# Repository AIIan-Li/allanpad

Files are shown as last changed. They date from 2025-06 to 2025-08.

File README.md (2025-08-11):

# allanpad

Allanpad is a 9 key macropad with a rotary encoder, and uses KMK firmware.

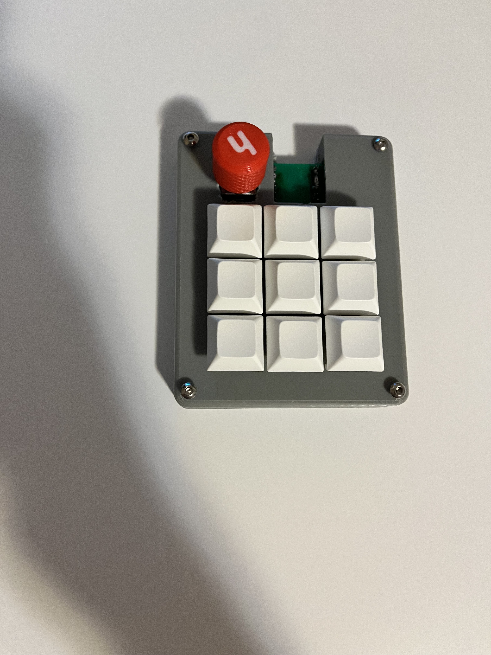
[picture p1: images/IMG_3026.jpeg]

## Features:
-3d printed case
-EC 11 Rotary encoder
-9 Keys

## CAD Model:
Everything goes together with 4 M3 screws for the case

It has the bottom part where the pcb goes and the top cover for it.

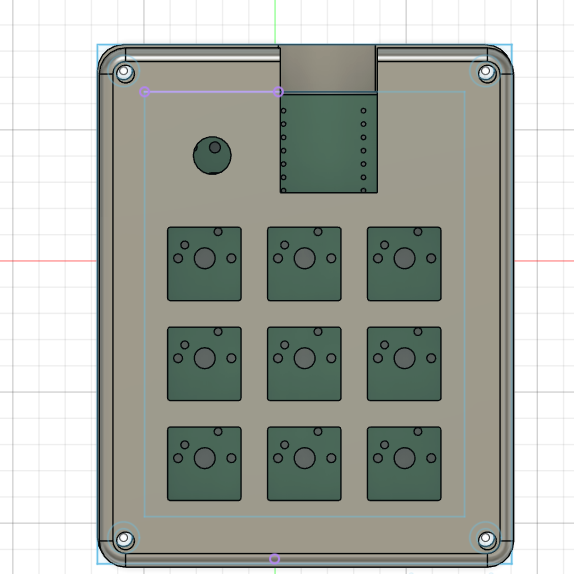
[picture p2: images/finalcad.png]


Made in Fusion360

## PCB
The PCB was created in KICAD

Schematic
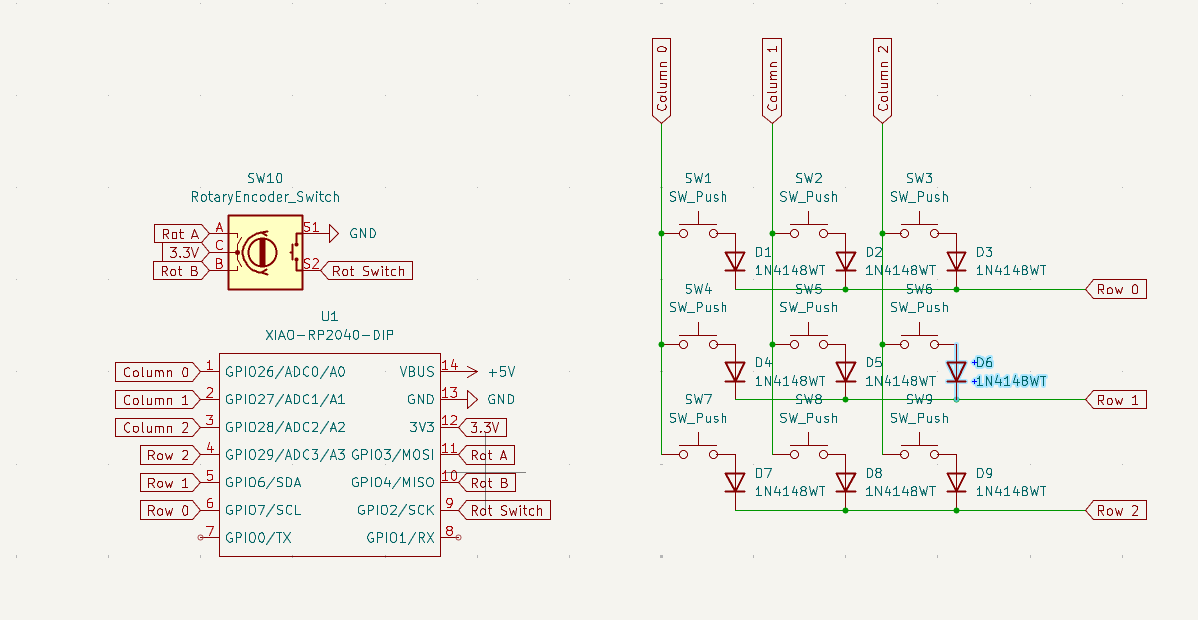
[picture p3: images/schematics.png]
schematic


PCB
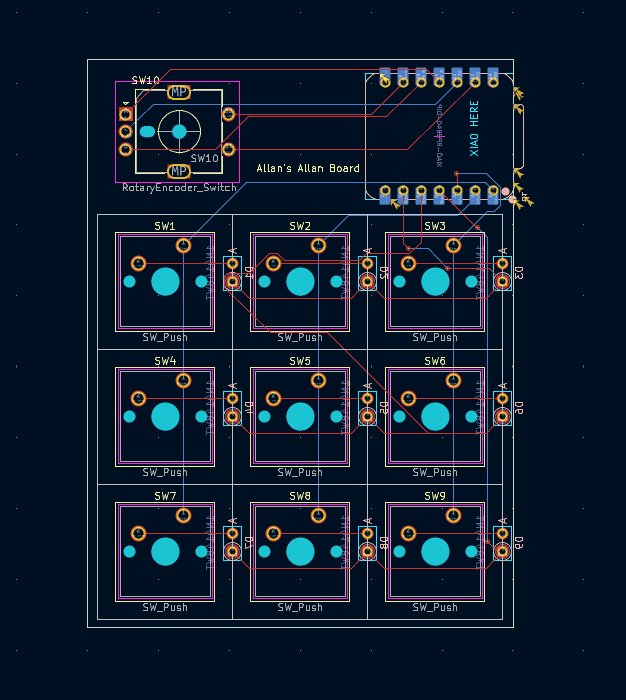
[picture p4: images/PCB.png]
PCB complete


## Firmware Overview
The hackpad uses kmk firmware for everything

- the rotary encoder changes volume. press to mute
- The 9 keys are macros that I can change

## BOM:
Everything needed to make the macropad

- 9x Cherry MX Switches
- 9x DSA Keycaps
- 4x M3x5x4 Heatset inserts
- 4x x16mm SHCS Bolts
- 9 1N4148 DO-35 Diodes.
- 1x EC11 Rotary Encoder
- 1x XIAO RP2040
- 1x Case (2 printed parts)

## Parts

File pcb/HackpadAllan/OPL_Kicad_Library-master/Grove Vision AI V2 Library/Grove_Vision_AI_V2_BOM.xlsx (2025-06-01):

Layer Jump | Number | Name | Specification | Operating Temperature | MPN Code | Quantity | Base | Plug Position | Process
N | 301010000 | SMD RES 0R-5%-1/16W;0402 |  | -55°C to 155°C | RC0402JR-070RL | 3 | 1 | R29,R30,R39 | SMT1
N | 301010004 | SMD RES 10K-5%-1/16W;0402 |  | -55°C to 155°C | RC0402JR-0710KL | 7 | 1 | R5,R7,R8,R23,R24,R31,R38 | SMT1
N | 301010008 | SMD RES 510K-5%-1/16W;0402 |  | -55°C to 155°C | RC0402JR-07510KL | 1 | 1 | R35 | SMT1
N | 301010456 | SMD RES 100K-1%-1/16W;0402 |  | -55°C to 155°C | RC0402FR-07100KL | 7 | 1 | R6,R10,R11,R16,R32,R33,R37 | SMT1
N | 301010495 | SMD RES;5.1K-1%-1/16W;0402 |  | -55°C to 155°C | RC0402FR-075K1L | 3 | 1 | R2,R3,R36 | SMT1
N | 301010746 | SMD RES 2.2K-1%-1/16W;0402 |  | -55°C to 155°C | RC0402FR-072K2L | 10 | 1 | R1,R4,R13,R14,R15,R19,R20,R21,R22,R40 | SMT1
N | 301011331 | SMD RES 22.1K-1%-1/16W;0402 |  | -55°C to 155°C | RC0402FR-0722K1L | 2 | 1 | R26,R34 | SMT1
N | 302010004 | SMD CAP Ceramic 100nF-16V-10%-X7R;0402 |  | -55°C to 125°C | CC0402KRX7R7BB104 | 18 | 1 | C5,C8,C13,C20,C21,C22,C23,C24,C25,C26,C27,C29,C30,C31,C32,C35,C36,C39 | SMT1
N | 302010006 | SMD CAP Ceramic 10nF-50V-10%-X7R;0402 |  | -55°C to 125°C | CC0402KRX7R9BB103 | 1 | 1 | C3 | SMT1
N | 302010049 | SMD CAP Ceramic 12pF-50V-5%-NPO;0402 |  | -55°C to 125°C | CC0402JRNPO9BN120 | 2 | 1 | C14,C15 | SMT1
N | 302010051 | SMD CAP Ceramic 220nF-16V-10%-X7R;0402 |  | -55°C to 125°C | CC0402KRX7R7BB224 | 1 | 1 | C16 | SMT1
N | 302010407 | SMD CAP Ceramic 4.7uF-10V-10%-X5R;0402 |  | -55°C to 85°C | CC0402KRX5R6BB475 | 7 | 1 | C4,C6,C7,C9,C10,C28,C34 | SMT1
N | 302010519 | SMD CAP Ceramic 10uF-10V-20%-X5R;0402 |  | -55°C to 85°C | CC0402MRX5R6BB106 | 2 | 1 | C11,C37 | SMT1
N | 302013249 | SMD CAP Ceramic 1uF-10V-10%-X5R;0402 |  | -55°C to 85°C | CL05A105KP5NNNC | 5 | 1 | C1,C2,C17,C18,C19 | SMT1
N | 303010544 | SMD Inductor 4.7uH-20%-1.1A;0806 |  | -40°C to 105°C | VLS201610HBX-4R7M-1 | 1 | 1 | L1 | SMT1
N | 303011858 | SMD Inductor 470nH-20%-2.6A;0603 |  | -40°C to 125°C | TFM160808ALC-R47MTAA | 2 | 1 | L2,L3 | SMT1
N | 304011053 | SMD Diode Schottky 40V-1A;SOD-323 |  |  | B5819WS SL | 4 | 1 | D1,D2,D3,D4 | SMT1
N | 304090121 | SMD LED Clear-Green;0402 | As posted |  | BL-HGE37A-AV-TRB | 1 | 1 | LED2 | SMT1
N | 304090746 | SMD LED Clear-Yellow;0402 | As posted |  | 16-213/Y2C-AN2Q1B/3T | 1 | 1 | LED1 | SMT1
N | 305030071 | SMD MOSFET N-CH 20V-500mA;SOT-523 |  |  | CJ1012 | 5 | 1 | Q1,Q2,Q3,Q4,Q5 | SMT1
N | 306011444 | SMD Crystal;24MHz-12pF-10ppm-4P-2.0*1.6*0.5mm |  | -40°C to 85°C | Y2400FE001 | 1 | 1 | X1 | SMT1
N | 310011697 | SMD IC MCU;Dual Cortex-M55 Core(Max 400MHz)-With a 400MHz NPU;WLCSP-65 | L5.58*W2.27mm | -40°C to 85°C | HX6538-A01TWA | 1 | 1 | U1 | SMT1
N | 310032794 | SMD IC PMIC;DCDC Buck-ADJ-2.2MHz-4A;DFN1.5×1.5-6 |  | -40°C to 85°C | SY80004DQD | 2 | 1 | U4,U6 | SMT1
N | 310032813 | SMD IC PMIC;LDO-1.8V-300mA;XTDFN-1*1-4L |  | -40°C to 125°C | SGM2036S-1.8XXDH4G/TR | 1 | 1 | U3 | SMT1
N | 310071431 | SMD IC Interface USB to High Speed TTL;QFN16 | USB to High-Speed Serial Port | -40°C to 85°C | CH343P | 1 | 1 | U2 | SMT1
N | 310091468 | SMD IC Memory;128Mbit-1.8V;SOIC-8 |  | -40°C to 85°C | W25Q128JWSIQ | 1 | 1 | U5 | SMT1
N | 311020009 | SMD Top Button 4N;4P-L4.6*W3.2*H2.5mm |  | -20°C to 70°C | SKRPADE010 | 1 | 1 | RST1 | SMT1
N | 311020518 | SMD Top Button 1.57N;4P-L4.6*W3.2*H2.5mm |  | -30°C to 85°C | SKRPABE010 | 1 | 1 | BOOT1 | SMT1
N | 312030502 | SMD DIGITAL MIC OMNI -26dBFS;OCLGA-4:3.5*2.65*0.94mm |  | -40˚C to 100˚C | MSM261D3526H1CPM | 1 | 1 | MIC1 | SMT1
N | 319015667 | PCB;Grove - Vision AI Module V2 -蓝油白字-4层 | 20*40*1.6mm-ENIG-FR4;Steel mesh code；404012305 |  |  | 1 | 1 |  | SMT1
N | 320011358 | SMD USB TYPE C-W/P;12+4P-8.94*7.35*3.26mm |  | -30°C to 85°C | USB-31C-F-16P-L7.35 | 1 | 1 | J1 | SMT1
N | 320031231 | DIP Black Female Header VERT;1*7P-2.54-5.0mm |  | -40℃ to 105℃ |  | 2 | 1 | P8,P9 | Unit
N | 320060904 | SMD FPC CONN Bottom Contact;15P-1.0mm;L19.9*W6.76*H2.0mm |  | -30°C to 85°C | ST-FPC-W102015-D | 1 | 1 | J2 | SMT1
N | 320090535 | SMD uSD Card Holder;9+4P-L11.25*W6.96*H1.42mm |  | -25°C to 70°C | ST-TF-MR267 | 1 | 1 | J5 | SMT1
N | 320110032 | SMD Grove Female Header-Beige;4P-2.0-90D | 2.0-4PHorizontal Mount with Locking Socket |  | PHS-4A horizontal mount | 1 | 1 | J3 | SMT1

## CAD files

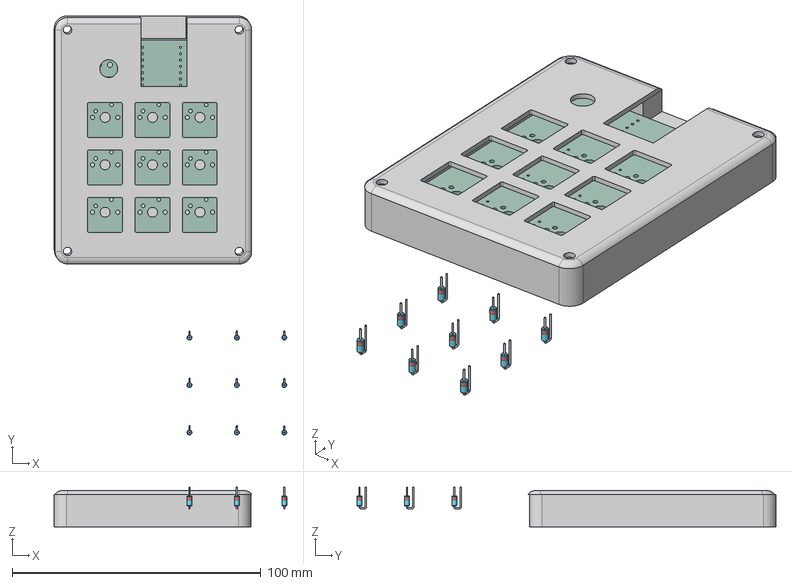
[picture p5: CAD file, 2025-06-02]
CAD/hackpad case.step
93.5 x 168.4 x 15.9 mm

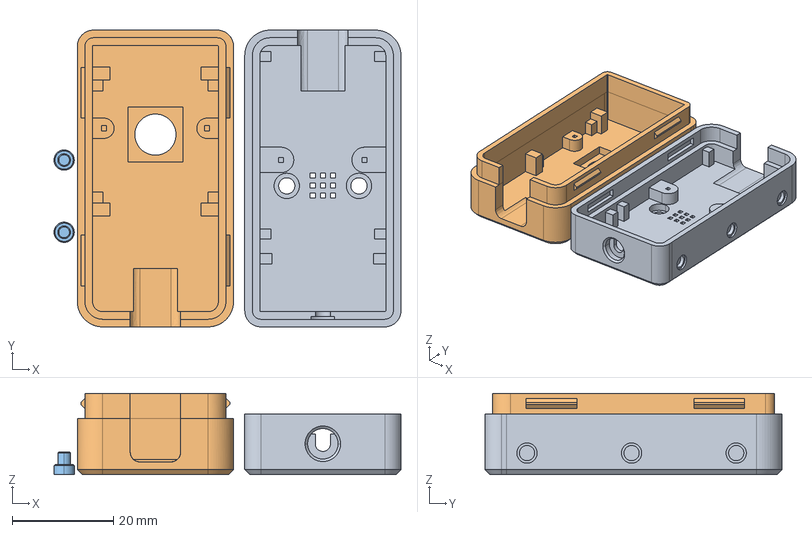
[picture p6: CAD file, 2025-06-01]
pcb/HackpadAllan/OPL_Kicad_Library-master/Grove Vision AI V2 Library/himax.stp
68.4 x 58.5 x 16.1 mm

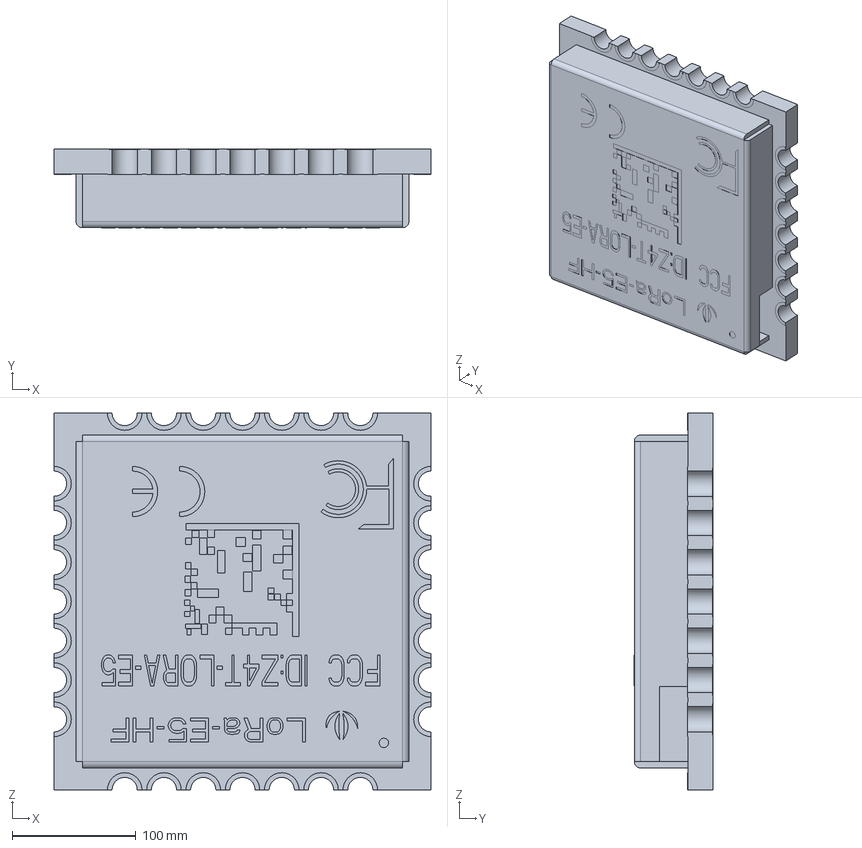
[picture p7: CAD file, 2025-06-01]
pcb/HackpadAllan/OPL_Kicad_Library-master/Seeed Studio Wio Series/Wio-E5-LE/LoRa-E5-LE-HF_3D_File.stp
304.8 x 63.8 x 304.8 mm

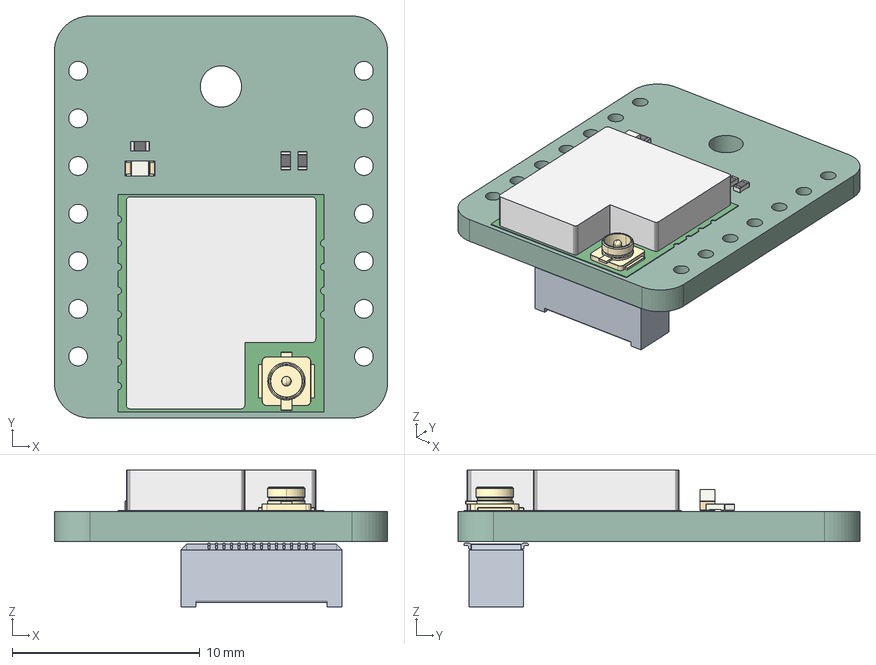
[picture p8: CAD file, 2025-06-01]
pcb/HackpadAllan/OPL_Kicad_Library-master/Seeed Studio Wio Series/Wio-SX1262/Wio-SX1262_for_XIAO_3D_file.step
17.8 x 21.4 x 7.30 mm
R_0402_1005Metric x 3
LED_0603_1608Metric
PCB
BF04-30pin-35H
Wio-SX1262 for XIAO V1.0_PCB

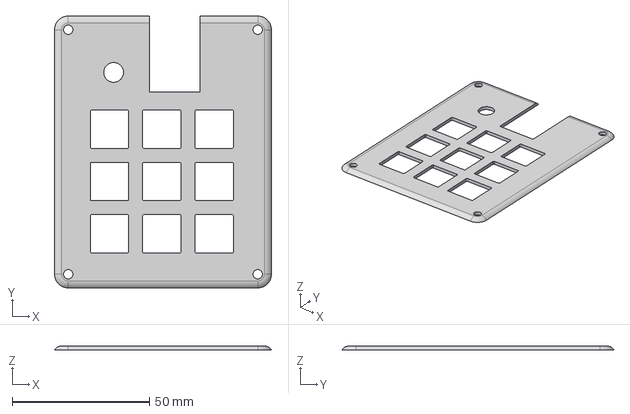
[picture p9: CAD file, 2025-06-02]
production/Case Top.step
79.0 x 99.0 x 1.50 mm

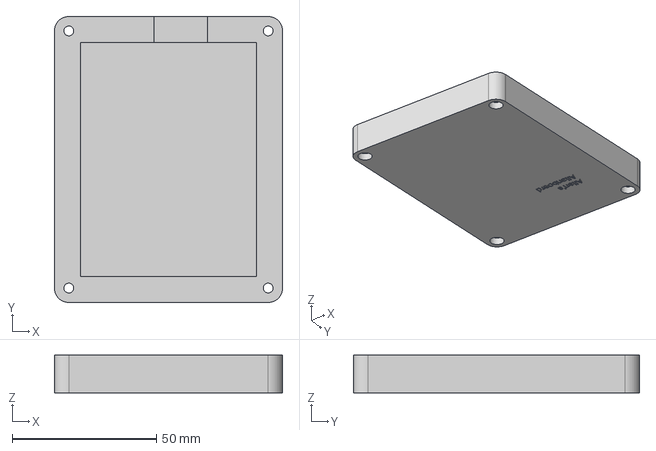
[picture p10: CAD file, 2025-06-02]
production/Case Bottom.step
79.0 x 99.0 x 13.0 mm

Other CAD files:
pcb/HackpadAllan/OPL_Kicad_Library-master/Grove Vision AI V2 Library/himax.3mf

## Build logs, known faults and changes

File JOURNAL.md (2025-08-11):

---
title: "Allanpad -Hackpad"
author: "Allan Li"
description: "a hackpad made for me, by me :)"
created_at: "2025-05-31"
---

#May 31: Making the Schematics 

Hi! this is my first ever hardware project, and although I don't believe Journaling is mandatory I thought it best to document everything. 
Finally installed OPL Kicad Library after 30 minutes, hopefully the entire process isnt this slow.
For my schematic [How to design Mechanical Keyboards PCBs with Kicad](https://www.youtube.com/watch?v=8WXpGTIbxlQ&t=320s&ab_channel=JoeScotto) was very helpful 

I knew how I wanted my macropad to look like, and after copying the HackClub tutorial exactly I decided to try again but this time creating a matrix

schematic

Honestly can say the hardest part of this was trying to find the correct footprint for the parts but I'm happy with what I learnt 
**Total time spent: 2H30min**

#May 31: Completing the PCB

At this point, I had to stop relying on tutorials and start problem solving on my own. Many things came up, especially when routing the traces.
I accidently moved the MCU then saved and closed Kicad, so wouldn't recommend as I had to reroute lots of things. 

PCB complete

**Total time spent 2H**

#May 32: Beginning the case

So I started off thinking that the case would be one of the easier steps of my process, but how wrong I was. 

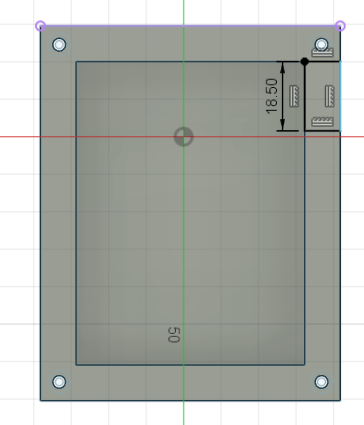
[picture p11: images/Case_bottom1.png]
Board base v1


Turns out my schematics woulddn't fit properly with the case, based off where I put the MCU and how it lined up with the holes.
I could either redesign the case, or fix the PCB which I figured would be better as to not create further problems later on. 

**Total time spent 2H**

#May 32: Refinishing the PCB

Initially It was going well, I rerouted the traces connected to the MCU, like 10 of them. 

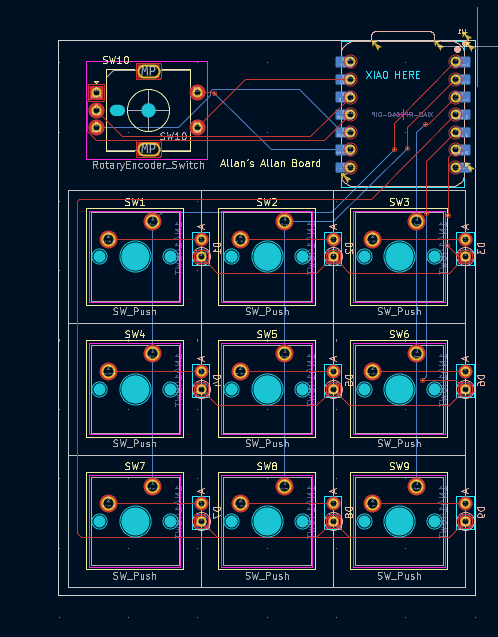
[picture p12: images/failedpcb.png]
failed PCB


Yeah so turns out I made the same mistake **again** 
I only rotated the MCU, instead of centering it to avoid interference with the case. Time to redo again.
also note: I actually made the biggest mistake ever I closed the window for some reason so I couldn't just revert my changes. 

Finally finished, I made sure to double check that nothing was going to interfere.
On the brightside, I learned a lot about routing traces, and I made sure to be more careful as I know If there was mistake I have to correct it. 

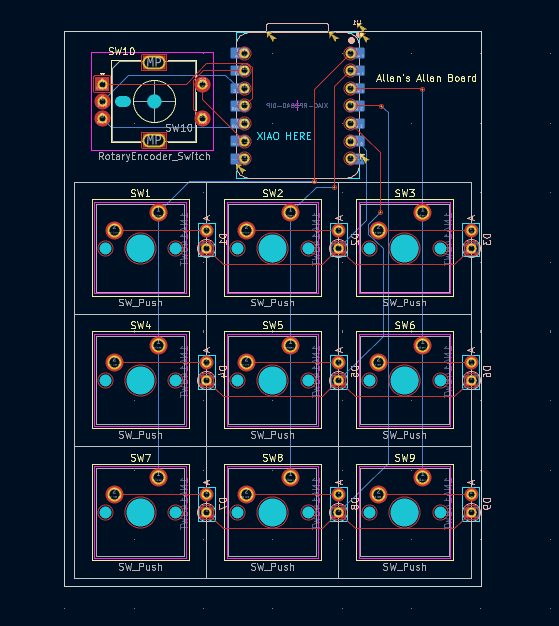
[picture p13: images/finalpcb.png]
Final Final PCB


**Total time spent 45min**

#May 32: Finishing the CAD

Mostly just working on it, not much to say



**Total time spent 2h**

#June 4: fixing my pcb 

Kind of odd, I got my project approved (please don't unapprove) then I go on hackpad website, **I used the wrong diode footprint**
Actually easier fix than I thought, I thankfully only had to reroute a few easy traces, and it doesn't impact any functions. 

pictureeee
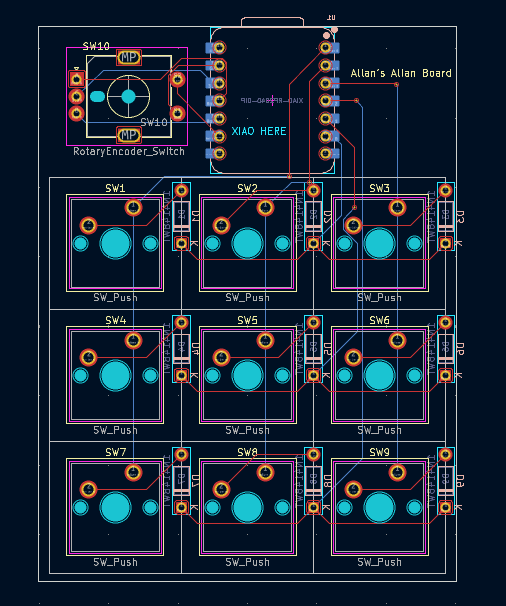
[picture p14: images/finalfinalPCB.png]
hopefully you don't need to see alt text


My gerber file for the pcb manufactuer finally got accepted after like 3 times so that's also cool
also just realised half of my journal entries are may 32 so lots of fun

**Total time spent 20min**

#July 4: doing the build

ok ik it is already into August, but when i started this project 2 months ago im like 99% sure you didn't need a journal for hackpad?? I made one anyways but here we are now and I kinda need to ship project for my travel stipend. The build was pretty easy and I can recall everything that happened but pls don't reject because I have no progress images.

So I started off by practicing soldering with one of the pcbs and a few extra switches/diodes
It was actually going pretty well so i started doing the hackpad.

It was around this point I realised I had made a circular cutout for the rotary encoder when I actually needed a square??? I thought about redoing the print but I kinda just took the solder and melted the case until the rot encoder fit. One thing I was really stupid about tho was when soldering the diodes and cutting the ends off for some reason I didn't grab the ends with a plier. Idk if that makes complete sense but basically I cut the excess of the diode off and the pieces just started flying. It's been two months and i'm still missing two pieces of wire but hopefully it isn't too bad. Other than that I didn't have any real problems with my hackpad, it was a pretty self explanatory assembly and my favourite part about it was snapping the swithces into the plate. I loaded firmware and everything was fine. Honestly don't exactly know what to talk about for the assembly cuz it just took a bit of time but wasn't actually that hard so hopefully this is detailed enough.

**Total time spent 4h**
also heres a picture of the finish product


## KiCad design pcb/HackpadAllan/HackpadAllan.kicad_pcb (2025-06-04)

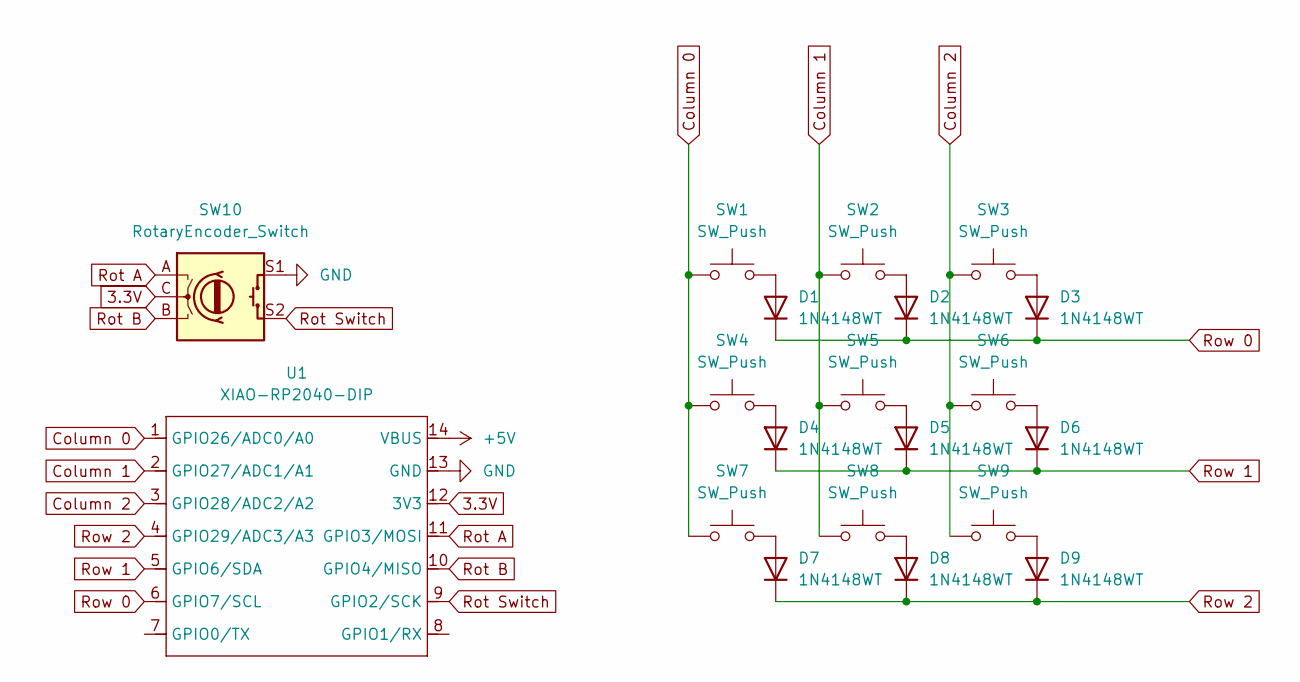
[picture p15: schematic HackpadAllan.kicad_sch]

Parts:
D1, D2, D3, D4, D5, D6, D7, D8, D9: 1N4148WT; D_DO-35_SOD27_P7.62mm_Horizontal
SW1, SW2, SW3, SW4, SW5, SW6, SW7, SW8, SW9: SW_Push; SW_Cherry_MX_1.00u_PCB
SW10: RotaryEncoder_Switch; RotaryEncoder_Alps_EC11E-Switch_Vertical_H20mm_MountingHoles
U1: XIAO-RP2040-DIP

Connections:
3.3V: SW10.C, U1.12 (3V3)
+5V: U1.14 (VBUS)
Column 0: SW1.1, SW4.1, SW7.1, U1.1 (GPIO26/ADC0/A0)
Column 1: SW2.1, SW5.1, SW8.1, U1.2 (GPIO27/ADC1/A1)
Column 2: SW3.1, SW6.1, SW9.1, U1.3 (GPIO28/ADC2/A2)
GND: SW10.S1, U1.13 (GND)
unnamed: D1.2 (A), SW1.2
unnamed: D2.2 (A), SW2.2
unnamed: D3.2 (A), SW3.2
unnamed: D4.2 (A), SW4.2
unnamed: D5.2 (A), SW5.2
unnamed: D6.2 (A), SW6.2
unnamed: D7.2 (A), SW7.2
unnamed: D8.2 (A), SW8.2
unnamed: D9.2 (A), SW9.2
Rot A: SW10.A, U1.11 (GPIO3/MOSI)
Rot B: SW10.B, U1.10 (GPIO4/MISO)
Rot Switch: SW10.S2, U1.9 (GPIO2/SCK)
Row 0: D1.1 (K), D2.1 (K), D3.1 (K), U1.6 (GPIO7/SCL)
Row 1: D4.1 (K), D5.1 (K), D6.1 (K), U1.5 (GPIO6/SDA)
Row 2: D7.1 (K), D8.1 (K), D9.1 (K), U1.4 (GPIO29/ADC3/A3)

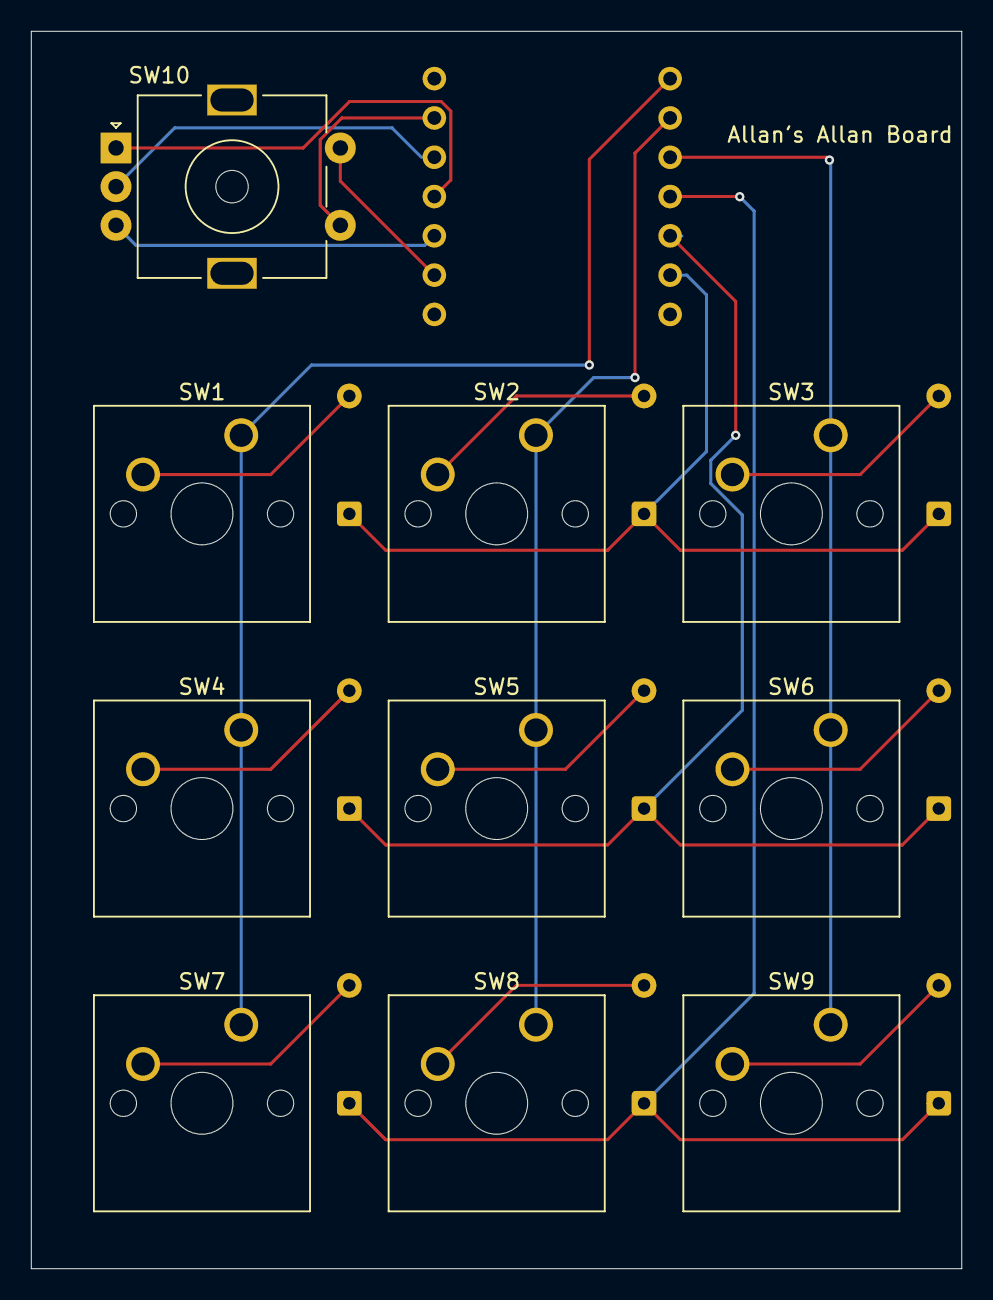
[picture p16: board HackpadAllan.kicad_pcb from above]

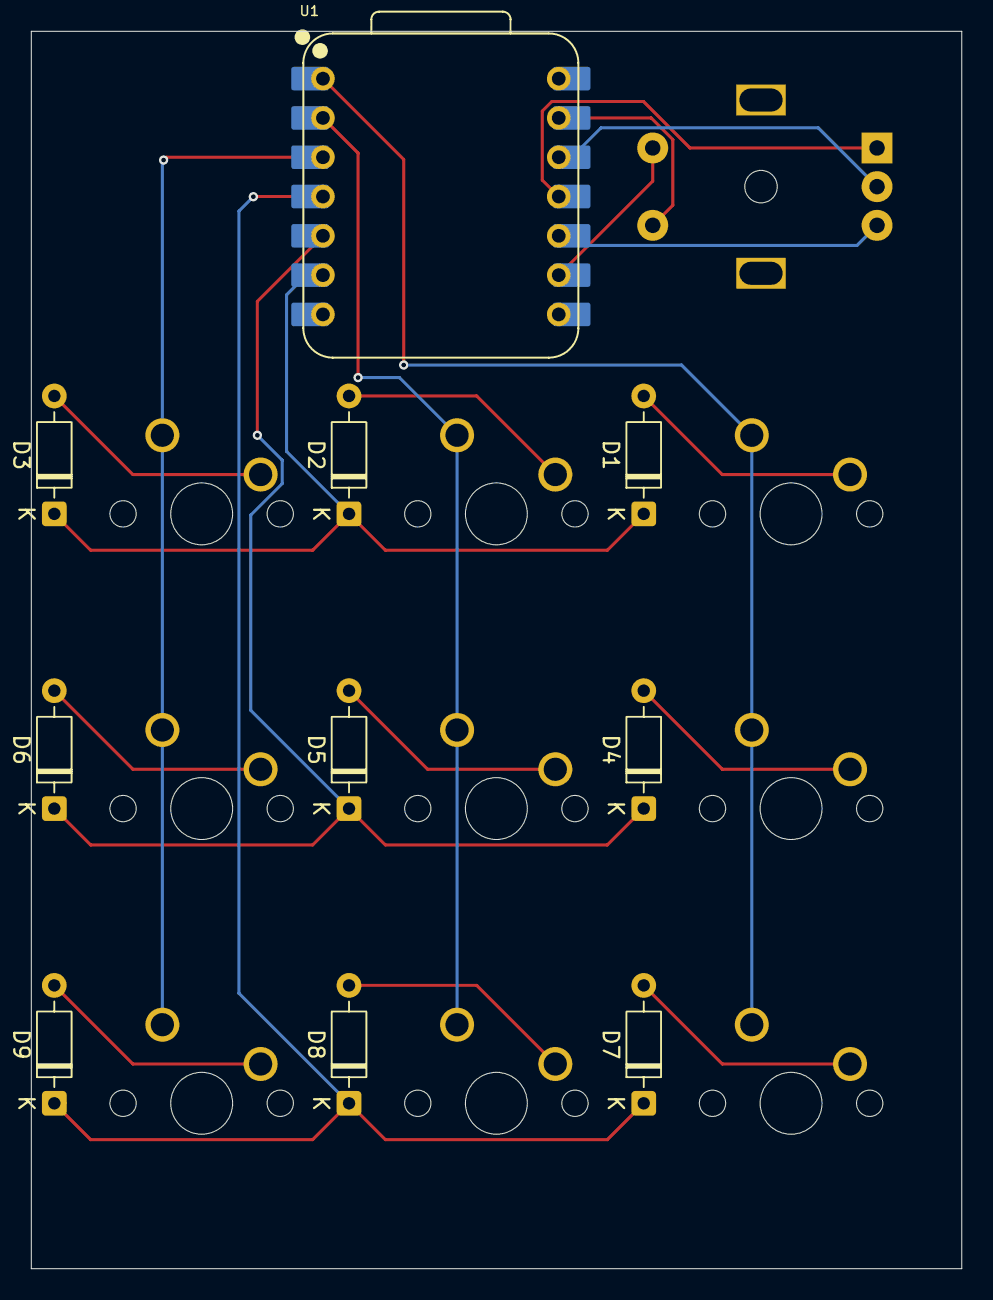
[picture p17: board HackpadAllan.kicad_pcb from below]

Board: 2 copper layers, 60.1 x 80.0 mm, 20 parts (10 on the bottom side), 20 nets.

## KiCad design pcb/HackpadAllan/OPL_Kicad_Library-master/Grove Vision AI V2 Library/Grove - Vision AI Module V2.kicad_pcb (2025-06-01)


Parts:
BOOT1: SW_Push; SW_Push_1P1T_NO_Vertical_Wuerth_434133025816
C1, C2, C17, C18, C19: 1uF; C0402
C3: 10nF; C0402
C4, C6, C7, C9, C10, C28, C34: 4.7uF; C0402
C5, C8, C13, C20, C21, C22, C23, C24, C25, C26, C27, C29, C30, C31, C32, C35, C36, C39: 100nF; C0402
C11, C37: 10uF; C0402
C14, C15: 12pF; C0402
C16: 220nF; C0402
D1, D2, D3, D4: B5819WS; D0805_SOD323
D5, D6, D7, D8: DNP; R0402; MPN DF2S6.8FS
J1: USB_C_Receptacle_USB2.0; USB2.0-TYPE-C
J2: Conn_01x15_MountingPin; FPC_DNC_15P_1.0mm
J3: Conn_01x04_MountingPin; 4P-SMD-2.0mm-RIGHT
J5: ST-TF-MR267; SD-TF-MR267; MPN SD-TF-MR267
L1: VLS201610HBX-4R7M-1; L0806
L2, L3: 470nH; L0603
LED1: Yellow; LED0402
LED2: Green; LED0402
M1: XIAO Connector/DNP; XIAO_Socket
MIC1: MSM261D3526H1CPM; MIC6P-3.5X2.65X0.94MM
Q1, Q2, Q3, Q4, Q5: CJ1012; SOT523
R1, R4, R13, R14, R15, R19, R20, R21, R22, R40: 2.2k; R0402
R2, R3, R36: 5.1k; R0402
R5, R7, R23, R24: 10k; R0402
R6, R16, R32, R33: 100K; R0402; Power Rating 1%; MPN RC0402JR-074K7L
R8, R31, R38: 10K; R0402; Power Rating 5%; MPN RC0402JR-074K7L
R9, R12, R17, R18, R25, R27, R28: DNP; R0402
R10, R11, R37: 100k; R0402
R26, R34: 22K; R0402; Power Rating 1%; MPN RC0402JR-074K7L
R29, R30, R39: 0R; R0402
R35: 510k; R0402
RST1: SW_Push; SW_Push_1P1T_NO_Vertical_Wuerth_434133025816
TP1, TP2, TP3: Test Point; TP-D35MIL; Part Type Test Point
U1: HX6538; WLCSP65_5.6x2.3x0.56mm
U2: CH343P; QFN-16-EP_3x3mm_P0.5mm_EP1x1mm
U3: WR0331-18FF4R; X2SON-4
U4, U6: SY80004DQD; DFN6-0.5-1.5X1.5X0.65MM; MPN SY80004DQD
U5: W25Q128JWSIQ; SOIC-8_5.23x5.23mm_P1.27mm
X1: 24MHz; 4P2016

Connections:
1V8: C13.1, C19.2, C20.1, C21.1, C28.1, C29.2, Q1.1 (G), Q2.1 (G), R5.1, R21.2, R22.2, R25.1, TP2.1 (T), U1.F3 (VDDIO_SIF1), U1.G3 (VDDA_RX), U1.H5 (VDDA_TX), U1.L2 (VDDIO_SIF2), U3.1 (OUT), U5.8 (VCC)
/0V9: C4.1, C7.1, L1.2, U1.L4 (DCDC_OUT)
BOOTOPT0: D3.1 (K), R11.1, U1.F4 (BOOT_OPT)
GND: C1.2, C2.2, C3.2, C4.2, C5.2, C6.2, C7.2, C8.1, C9.2, C10.2, C11.1, C13.2, C14.2, C15.1, C17.2, C18.2, C19.1, C20.2, C21.2, C22.2, C23.2, C24.1, C25.1, C26.2, C27.1, C28.2, C29.1, C30.1, C31.2, C34.2, C35.1, C37.1, C39.1, D5.1, D6.1, D7.1, D8.1, J1.A1_B1_A12_B12 (GND), J1.S1 (SHIELD), J2.1, J2.4, J2.7, J2.10, J2.MP (MountPin), J3.4, J3.MP (MountPin), J5.S1 (SHD1), J5.S2 (SHD2), J5.S3 (SHD3), J5.S4 (SHD4), J5.T6 (VSS), LED2.1 (K), M1.13 (GND), MIC1.4 (GND), MIC1.5 (L/R), MIC1.6 (GND), Q3.2 (S), R2.2, R3.2, R10.2, R11.2, R23.2, R26.1, R34.1, R37.2, RST1.2, TP3.1 (T), U1.C5 (GND1), U1.G4 (GND2), U1.H3 (GND3), U1.L3 (GND4), U1.M2 (GND5), U1.M4 (GND6), U2.2 (GND), U2.17 (EPAD), U3.2 (GND), U3.T (GND), U4.4 (GND), U5.4 (GND), U6.4 (GND), X1.2 (1), X1.4 (3)
GROVE_5V_IN: C18.1, C34.1, C35.2, J3.3, R14.1, R15.1, R31.2, R32.2, U6.6 (IN)
I2CS0_SCL/5V: J3.1, Q4.3 (D), R14.2
I2CS0_SDA/5V: J3.2, Q5.3 (D), R15.2
M_3V3_SCL: J2.13, Q1.3 (D), R19.2
M_3V3_SDA: J2.14, Q2.3 (D), R20.2
unnamed: BOOT1.2, R4.2
unnamed: D1.2 (A), R36.2
unnamed: C9.1, C10.1, C27.2, D2.1 (K), D4.1 (K), R6.2, R8.2, U4.6 (IN)
unnamed: BOOT1.1, D3.2 (A), R36.1
unnamed: J1.A5 (CC1), R2.1
unnamed: J1.B5 (CC2), R3.1
unnamed: LED1.2 (A), R38.1
unnamed: LED1.1 (K), Q3.3 (D)
unnamed: LED2.2 (A), R24.2
unnamed: M1.12 (3V3), R39.2
unnamed: MIC1.2 (CLK), R29.1
unnamed: MIC1.3 (DATA), R30.1
unnamed: Q3.1 (G), R37.1, R40.2
unnamed: R10.1, U1.E4 (TEST_MODE)
unnamed: L1.1, U1.L5 (VX1)
unnamed: C14.1, R35.1, U1.G2 (XTAL_24M_I), X1.3 (4)
unnamed: C15.2, R35.2, U1.F1 (XTAL_24M_O), X1.1 (2)
unnamed: C16.2, U2.13 (RTS)
unnamed: R8.1, U4.1 (EN)
unnamed: C32.1, R16.1, R26.2, U4.3 (FB)
unnamed: L2.1, U4.5 (LX)
unnamed: R6.1, U4.2 (PG)
unnamed: R31.1, U6.1 (EN)
unnamed: C36.1, R33.1, R34.2, U6.3 (FB)
unnamed: L3.1, U6.5 (LX)
unnamed: R32.1, U6.2 (PG)
PA0/3V3: M1.1 (D0/A0), U1.D4 (PA0)
PA1/VMUTE/3V3: J2.11, U1.C4 (PA1)
PA2/I2CS0_SCL/3V3: M1.6 (D5/SCL), Q4.2 (S), R1.1, R17.2, U1.A4 (PA2)
PA3/I2CS0_SDA/3V3: M1.5 (D4/SDA), Q5.2 (S), R13.1, R18.2, U1.B4 (PA3)
PB0/RX0/3V3: U1.A5 (PB0), U2.4 (TXD)
PB1/TX0/3V3: U1.B5 (PB1), U2.5 (RXD)
PB2/SSPIM_DO/3V3: D7.2, J5.T3 (CMD), M1.11 (D10/MOSI), R12.2, U1.N5 (PB2)
PB3/SSPIM_DI/3V3: D5.2, J5.T7 (DAT0), M1.10 (D9/MISO), R9.2, U1.M3 (PB3)
PB4/SSPIM_SCLK/3V3: D6.2, J5.T5 (CLOCK), M1.9 (D8/SCK), R27.2, U1.N4 (PB4)
PB5/SSPIM_~CS/3V3: D8.2, J5.T2 (CD/DAT3), R28.2, U1.N3 (PB5)
PB6/UART1_RX/3V3: M1.7 (D6/TX), U1.N1 (PB6)
PB7/UART1_TX/3V3: M1.8 (D7/RX/SS), U1.M1 (PB7)
PB8/3V3: M1.3 (D2/A2), U1.L1 (PB8)
PB9/PDM_CLK/3V3: R29.2, U1.F5 (PB9)
PB10/PDM_DATA0/3V3: R30.2, U1.G5 (PB10)
PB11/3V3: M1.2 (D1/A1), U1.J3 (PB11)
QSPI_CLK: U1.C2 (QSPI_CLK), U5.6 (CLK)
QSPI_CS: R5.2, U1.B2 (QSPI_CS), U5.1 (~CS)
QSPI_D0: U1.B1 (QSPI_DIO0), U5.5 (DI(IO0))
QSPI_D1: U1.D3 (QSPI_DIO1), U5.2 (DO(IO1))
QSPI_D2: U1.A1 (QSPI_DIO2), U5.3 (IO2)
QSPI_D3: U1.E3 (QSPI_DIO3), U5.7 (IO3)
RST: C3.1, C16.1, M1.4 (D3/A3), R7.1, RST1.1, U1.E5 (RESETN)
RX_CK_N: J2.8, U1.E2 (RX_CKN)
RX_CK_P: J2.9, U1.F2 (RX_CKP)
RX_D0_N: J2.2, U1.D2 (RX_DN0)
RX_D0_P: J2.3, U1.C1 (RX_DP0)
RX_D1_N: J2.5, U1.D1 (RX_DN1)
RX_D1_P: J2.6, U1.E1 (RX_DP1)
SEN_D1/SD~INSERT: J5.G1 (SWITCH), R25.2, U1.G1 (SEN_D1)
SEN_I2CM_SCL: Q1.2 (S), R21.1, U1.A3 (SEN_I2CM_SCL)
SEN_I2CM_SDA: Q2.2 (S), R22.1, U1.B3 (SEN_I2CM_SDA)
UD+: J1.A6 (D+), J1.B6 (D+), U2.7 (D+)
UD-: J1.A7 (D-), J1.B7 (D-), U2.8 (D-)
USER_LED/1V8: R40.1, U1.K2 (SEN_D2)
USR_BTN/1V8: D1.1 (K), R23.1, U1.H1 (SEN_D0)
V33IO: C2.1, C31.1, U2.1 (VIO), U2.6 (V3)
VBUS: C1.1, C30.2, D4.2 (A), J1.A4_B4_A9_B9 (VBUS), U2.3 (VDD5), U2.9 (VBUS)
VCC_3V3: C5.1, C6.1, C8.2, C11.2, C17.1, C22.1, C23.1, C24.2, C25.2, C26.1, C32.2, C36.2, C37.2, C39.2, J2.15, J5.T4 (VDD), L2.2, L3.2, MIC1.1 (VDD), Q4.1 (G), Q5.1 (G), R1.2, R4.1, R7.2, R9.1, R12.1, R13.2, R16.2, R17.1, R18.1, R19.1, R20.1, R24.1, R27.1, R28.1, R33.2, R38.2, R39.1, TP1.1 (T), U1.D5 (VDDIO_AON), U1.M5 (VDDA_DCDC), U1.N2 (VDDIO_PIF), U3.3 (EN), U3.4 (IN)
VMAIN: D2.2 (A), M1.14 (VUSB)

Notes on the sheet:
MIPI CSI
AON 3V3
MIPI DSI
PIF 3V3
SIF only 1V8
Imax=600mA
23/11/14
Grove - Vision AI Module V2
JN.FUONG



Board: 4 copper layers, 40.0 x 20.0 mm, 112 parts (31 on the bottom side), 75 nets.

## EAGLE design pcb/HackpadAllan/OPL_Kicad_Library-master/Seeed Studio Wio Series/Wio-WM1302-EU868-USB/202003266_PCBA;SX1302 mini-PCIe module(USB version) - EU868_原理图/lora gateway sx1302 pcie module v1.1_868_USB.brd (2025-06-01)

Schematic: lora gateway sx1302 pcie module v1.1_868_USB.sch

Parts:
ANT1: U.FL-R-SMT-1(10); U-FL3P-SMD-2.6X2.6X1.0MM
ANT2: DNP; U-FL3P-SMD-2.6X2.6X1.0MM
C1, C12, C15, C19, C23, C25, C26, C29, C32, C41, C43, C45, C65, C67, C80, C83, C86, C88: 100nF; C0402
C2, C75: 2.2pF; C0402
C3, C92: 10uF; C0603
C4, C8, C11, C16, C17, C18, C64: 56pF; C0402
C5, C6, C9, C10: 3.6pF; C0402
C7, C91: 5.6pF; C0402
C13, C20, C21, C24, C28, C35, C39, C40, C42, C44, C47, C48, C76, C87, C89: 1uF; C0402
C14, C38, C57, C66, C81, C84: 10pF; C0402
C22, C27, C33: 10uF; C0603@1
C30, C56, C74, C77, C78, C79: DNP; C0402
C31: DNP; C0603@1
C34, C46, C63: 470nF; C0402
C36: 47nF; C0402
C37: 47pF; C0402
C49: 4.7uF; C0603
C50, C62, C85: 10nF; C0402
C51: 1nF; C0402
C52, C55: 100pF; C0402
C53, C60, C61: 3.3pF; C0402
C54: 39pF; C0402
C58: 1.3pF; C0402
C59, C68, C73: 1.8pF; C0402
C69, C70, C71, C72: 10uF; C0805
C82: 2.7pF; C0402
C90: 2.2uF; C0603
D1, D4: Green; LED-0402
D2: Red; LED-0402
D3: Blue; LED-0402
D5: LXES15AAA1-153; ESD-0402
D6: DNP; ESD-0402
D7: BAT54XV2T1G; SOD-523
FB1: BLM15PD121SN1D; F0402
J1: DNP; PCIE52P-0.8-50.95X30MM
L1: LQP15MN1N2B02D; L0402
L2: LQW15AN6N8G00D; L0402
L4: 0R; F0603
L5: LQH44PN1R0NP0L; L4.4X3.0MM
L6, L14, L20: MLZ2012M150WT; L0805
L7, L15, L18, L21: DNP; L0402
L8: LQW15AN3N0B00; L0402
L9: LQW15AN47NJ00D; L0402
L10: LQW15AN2N5B00D; L0402
L11: LQW15AN4N7C00D; L0402
L12, L13: LQW15AN12NG00D; L0402
L16: LQW15AN7N5G00D; L0402
L17, L24: LQW15AN5N6C10D; L0402
L22: LQW15AN15NG00D; L0402
Q8: CJ2101; SOT-323
Q10: CJ2102; SOT-323
R1, R4, R33, R34, R38, R42, R57, R65, R71: 10k; R0402
R2, R7: 0R; R0603
R3, R8, R11, R12, R43, R44, R46, R49, R51, R55, R56, R59, R60, R61, R62, R63, R67, R70, R72, R73, R74, R75, R76, R81: DNP; R0402
R5, R10, R14, R15, R16, R39, R40, R41: 100R; R0402
R6, R9, R37: 220R; R0402
R13, R35, R52: DNP; R0603
R17, R18, R19, R20, R21, R22, R23, R24, R25, R26, R27, R28, R29, R36, R45, R48, R50, R53, R54, R69, R77: 0R; R0402
R30, R31, R32: 680R; R0402
R47, R79: 1k; R0402
R58, R68: 4.7k; R0402
R64, R66: 22R; R0402
R78, R82: 100k; R0402
R80: 10R; R0402
R83, R87: 200k_1%; R0402
S1, S2, S3, S4, S5, S6: 323030226; SHIELD_CLIP
TP1, TP2, TP3, TP4, TP5, TP6, TP7, TP8, TP9, TP10, TP14: TEST-POINT-35; TP_3535
TP15: TEST-POINT'4545'; TP-D45MIL
U1: SX1302IMLTRT; QFN68-0.35-7X7X0.75MM
U2, U8, U10: HDF866A3-S6; FILTER6P-1.1-3X3X1.3MM
U3, U4: DNP; SOT-23-5
U5, U7: SX1250IMLTRT; QFN24G-0.5-4X4MM
U6: MP2161GJ; TSOT23-8
U9: SKY66420-11; MODULE16P-0.5-3X3X0.75MM
U11: SX1262IMLTRT; QFN24G-0.5-4X4MM
U12: STM32L412K8U6; UFQFPN32-0.5-5X5MM
U13: STTS751; UDFN-6L
X1: DSB221SDN; X4-SMD-2.5X2.0X1.0MM
X3: 32.768kHz; X2-SMD-3.2X1.5X0.55MM

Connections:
32MHZ: R6.2, R9.2, R37.2, X1.3 (OUT)
1302_CS: R33.2, R43.1, U1.1 (HOST_CSN), U12.10 (PA4)
1302_RESET: C1.2, D7.-, R1.2, U1.7 (RESET), U12.8 (PA2)
1302_RESET_HOST: D7.+, R59.1
CONFIG_OK: R31.1, U1.66 (GPIO0)
DM: J1.36, R66.1
DP: J1.38, R64.1
FEM_CS: R14.2, R34.1, U1.10 (RADIO_CTRL0), U3.3 (CE)
FEM_PA_ON: R15.2, U1.16 (RADIO_CTRL4)
GND: ANT1.GND1, ANT1.GND2, ANT2.GND1, ANT2.GND2, C2.1, C3.1, C5.1, C7.1, C9.1, C12.1, C13.1, C15.1, C16.1, C17.1, C18.1, C19.1, C20.1, C21.1, C22.1, C23.1, C24.1, C25.1, C26.1, C27.1, C28.1, C29.1, C30.1, C31.1, C32.1, C33.1, C34.1, C35.1, C36.1, C37.1, C39.1, C40.1, C41.1, C42.1, C43.1, C44.1, C45.1, C46.1, C47.1, C48.1, C49.1, C50.1, C51.1, C52.1, C55.1, C56.1, C57.1, C58.1, C60.2, C61.2, C62.1, C63.2, C65.2, C67.2, C69.1, C70.1, C71.1, C72.1, C73.2, C74.2, C76.1, C77.2, C78.2, C80.1, C81.2, C82.2, C83.1, C84.2, C85.1, C86.1, C87.1, C88.1, C89.1, C90.1, C92.1, D1.-, D2.-, D3.-, D4.-, D5.1, D6.1, J1.4 (GND), J1.9 (GND), J1.15 (GND), J1.18 (GND), J1.21 (GND), J1.26 (GND), J1.27 (GND), J1.29 (GND), J1.34 (GND), J1.35 (GND), J1.37 (GND), J1.40 (GND), J1.43 (GND), J1.50 (GND), J1.S1 (GND), J1.S2 (GND), Q10.2 (S), R1.1, R4.1, R11.1, R12.1, R17.2, R53.1, R53.2, R54.1, R54.2, R55.1, R55.2, R57.2, R73.1, R74.1, R74.2, R87.1, S1.S1, S1.S2, S1.S3, S1.S4, S1.S5, S2.S1, S2.S2, S2.S3, S2.S4, S2.S5, S3.S1, S3.S2, S3.S3, S3.S4, S3.S5, S4.S1, S4.S2, S4.S3, S4.S4, S4.S5, S5.S1, S5.S2, S5.S3, S5.S4, S5.S5, S6.S1, S6.S2, S6.S3, S6.S4, S6.S5, TP3.T, U1.6 (GND), U1.9 (GND), U1.15 (GND), U1.24 (GND), U1.25 (GND), U1.39 (GND), U1.46 (GND), U1.55 (GND), U1.62 (GND), U1.69 (GND), U2.1 (GND), U2.3 (GND), U2.4 (GND), U2.6 (GND), U3.2 (VSS), U4.2 (VSS), U5.7 (GND), U5.20 (GND), U5.PAD, U6.4 (PGND), U6.6 (AGND), U7.7 (GND), U7.20 (GND), U7.PAD, U8.1 (GND), U8.3 (GND), U8.4 (GND), U8.6 (GND), U9.10 (GND), U9.12 (GND), U9.17 (EPAD), U10.1 (GND), U10.3 (GND), U10.4 (GND), U10.6 (GND), U11.2 (GND), U11.5 (GND), U11.8 (GND), U11.20 (GND), U11.PAD, U12.16 (VSS), U12.32 (VSS), U12.PAD, U13.4 (ADDR/!THERM), U13.5 (GND), X1.2 (GND)
HOST_CS0: J1.51, R43.2
HOST_CS1: J1.25, R51.2
HOST_IO1: J1.33, R61.2
HOST_IO2: J1.31, R63.2
HOST_IO3: J1.23
HOST_IO4: J1.8, R67.2
HOST_IO5: J1.10, R60.2
HOST_IO6: J1.12
HOST_MISO: R39.1, R44.2
HOST_MOSI: J1.49, R46.2
HOST_RST: J1.22, R59.2, R77.2
HOST_SCK: J1.45, R49.2
I2C_SCL: R68.2, R76.1, R81.1, U12.29 (PB6), U13.1 (SCL)
I2C_SDA: R58.2, R70.1, R75.1, U12.30 (PB7), U13.6 (SDA)
MCU_RESET: C85.2, R71.2, R77.1, TP5.T, U12.4 (NRST)
MISO: R44.1, R45.1, U1.2 (HOST_MISO), U11.16 (MISO)
MISO_A: U1.42 (RADIO_A_MISO), U5.16 (MISO)
MISO_B: U1.33 (RADIO_B_MISO), U7.16 (MISO)
MOSI: R5.2, R40.2, R46.1, R48.1
MOSI_A: U1.67 (RADIO_A_MOSI), U5.17 (MOSI)
MOSI_B: U1.19 (RADIO_B_MOSI), U7.17 (MOSI)
unnamed: C11.2, U9.2 (RX)
unnamed: TP15.T, U6.1 (PG)
unnamed: C8.1, R11.2, R52.2, U8.5 (OUT)
unnamed: C2.2, L11.2, R52.1, U8.2 (IN)
unnamed: C11.1, R13.2, U2.2 (IN)
unnamed: C4.2, U9.1 (TX)
unnamed: C68.1, C74.1, C75.2
unnamed: C65.1, L18.2, R36.2, U11.1 (VDD_IN)
unnamed: C66.2, R37.1
unnamed: L5.1, U6.3 (SW)
unnamed: R83.1, R87.2, U6.7 (FB)
unnamed: R3.1, R4.2, X1.1 (ENABLE)
unnamed: C14.1, U5.3 (XTA)
unnamed: C62.2, L4.1, R3.2, X1.4 (VDD)
unnamed: R5.1, U1.3 (HOST_MOSI)
unnamed: D4.+, R47.2
unnamed: R10.1, U1.4 (HOST_SCK)
unnamed: R82.2, U6.8 (EN)
unnamed: R8.1, U4.3 (CE)
unnamed: C14.2, R6.1
unnamed: L6.2, U5.8 (DCC_SW)
unnamed: C34.2, L6.1, L7.2, U5.6 (VREG)
unnamed: C64.1, C82.1, L24.2
unnamed: R19.1, U1.34 (RADIO_B_CLK_I)
unnamed: C16.2, R14.1, U9.4 (CSD)
unnamed: C38.1, U7.3 (XTA)
unnamed: C36.2, C37.2, L9.2, U5.1 (VR_PA)
unnamed: C38.2, R9.1
unnamed: L14.2, U7.8 (DCC_SW)
unnamed: C46.2, L14.1, L15.2, U7.6 (VREG)
unnamed: C54.2, L11.1
unnamed: C7.2, C53.2, C54.1, L10.2
unnamed: C4.1, C8.2, R12.2
unnamed: C17.2, R15.1, U9.5 (CPS)
unnamed: C18.2, R16.1, U9.6 (CTX)
unnamed: R17.1, U1.20 (SP_VALID)
unnamed: R18.1, U1.32 (RADIO_B_IQ3)
unnamed: R20.1, U1.35 (RADIO_B_IQ0)
unnamed: R24.1, U1.41 (RADIO_A_IQ3)
unnamed: R21.1, U1.36 (RADIO_B_IQ1)
unnamed: R22.1, U1.37 (RADIO_B_IQ4)
unnamed: R23.1, U1.38 (RADIO_B_IQ2)
unnamed: R25.1, U1.43 (RADIO_A_CLK_I)
unnamed: R26.1, U1.44 (RADIO_A_IQ0)
unnamed: R27.1, U1.45 (RADIO_A_IQ1)
unnamed: R28.1, U1.48 (RADIO_A_IQ4)
unnamed: R29.1, U1.49 (RADIO_A_IQ2)
unnamed: D3.+, R32.2
unnamed: D2.+, R31.2
unnamed: D1.+, R30.2
unnamed: Q8.1 (G), Q10.3 (D), R78.2
unnamed: C1.1, R80.1
unnamed: L1.1, U9.16 (VCC1)
unnamed: L2.1, L8.1, U9.13 (PA_OUT)
unnamed: C56.2, C57.2, L8.2, L16.1
unnamed: C58.2, L16.2, U9.11 (TX_IN)
unnamed: C59.2, C60.1, L17.1, U9.9 (ANT)
unnamed: C61.1, C91.1, L17.2, L24.1
unnamed: C66.1, U11.3 (XTA)
unnamed: ANT1.D, C64.2, D5.2
unnamed: R35.2, R62.1, R69.2, U10.2 (IN)
unnamed: C63.1, L18.1, L20.1, U11.7 (VREG)
unnamed: R35.1, U9.7 (LNA_IN), U10.5 (OUT)
unnamed: L20.2, U11.9 (DCC_SW)
unnamed: J1.47, R39.2
unnamed: R40.1, U11.17 (MOSI)
unnamed: R41.1, U11.18 (SCK)
unnamed: C6.1, C10.1, C75.1, R13.1, U2.5 (OUT)
unnamed: R69.1, U9.8 (RX_FLT)
unnamed: C78.1, C79.1, L21.2
unnamed: ANT2.D, C79.2, D6.2
unnamed: C59.1, C91.2
unnamed: C77.1, L21.1, R62.2
unnamed: R65.2, U13.2 (!EVENT)
unnamed: C52.2, FB1.1, L1.2, U9.15 (VCC0)
unnamed: R64.2, U12.22 (PA12)
unnamed: R66.2, U12.21 (PA11)
unnamed: C92.2, Q10.1 (G), R79.2
unnamed: R56.2, R57.1, U12.31 (BOOT0)
unnamed: R72.2, R73.2, U12.6 (PA0-CLK_IN)
unnamed: C81.1, U12.2 (PC14-OSC32_IN), X3.2
unnamed: C84.1, U12.3 (PC15-OSC32_OUT), X3.1
unnamed: J1.14, R76.2
unnamed: J1.16, R70.2
unnamed: J1.30, R81.2
unnamed: J1.32, R75.2
PPS: J1.19, TP2.T, U1.8 (PPS), U12.27 (PB4)
RADIO_A_CLK_32M: R25.2, R72.1, U5.14 (BUSY)
RADIO_A_CLK_O: R28.2, U5.11 (DIO5)
RADIO_A_CSN: U1.68 (RADIO_A_CSN), U5.19 (NSS)
RADIO_A_IQ_0: R26.2, U5.13 (DIO1)
RADIO_A_IQ_1: R27.2, U5.12 (DIO2)
RADIO_A_IQ_2: R29.2, U5.5 (DIO3)
RADIO_A_IQ_3: R24.2, U5.21 (DIO4)
RADIO_A_RESET: U1.13 (RADIO_CTRL3), U5.15 (NRESET)
RADIO_A_RFIN: C6.2, L12.2, U5.23 (RFI_N)
RADIO_A_RFIP: C5.2, L12.1, U5.22 (RFI_P)
RADIO_B_CLK_32M: R19.2, U7.14 (BUSY)
RADIO_B_CLK_O: R22.2, U7.11 (DIO5)
RADIO_B_CSN: U1.18 (RADIO_B_CSN), U7.19 (NSS)
RADIO_B_IQ0: R20.2, U7.13 (DIO1)
RADIO_B_IQ_1: R21.2, U7.12 (DIO2)
RADIO_B_IQ_2: R23.2, U7.5 (DIO3)
RADIO_B_IQ_3: R18.2, U7.21 (DIO4)
RADIO_B_RESET: U1.28 (RADIO_CTRL9), U7.15 (NRESET)
RADIO_B_RFIN: C10.2, L13.2, U7.23 (RFI_N)
RADIO_B_RFIP: C9.2, L13.1, U7.22 (RFI_P)
RFO: C53.1, L9.1, L10.1, U5.24 (RFO)
RX_ON: R32.1, U1.59 (GPIO4)
SCK: R10.2, R41.2, R49.1, R50.1
SCK_A: U1.65 (RADIO_A_SCK), U5.18 (SCK)
SCK_B: U1.21 (RADIO_B_SCK), U7.18 (SCK)
STM32_MISO: R45.2, U12.12 (PA6)
STM32_MOSI: R48.2, U12.13 (PA7)
STM32_SCK: R50.2, U12.11 (PA5)
SWCLK: TP7.T, U12.24 (PA14)
SWDIO: TP8.T, U12.23 (PA13)
SX1261_BUSY: R67.1, U11.14 (BUSY), U12.9 (PA3)
SX1261_CS: R42.1, R51.1, U11.19 (NSS), U12.14 (PB0)
SX1261_IO1: R61.1, U1.54 (GPIO7), U11.13 (DIO1), U12.15 (PB1)
SX1261_IO2: R63.1, U11.12 (DIO2)
SX1261_IO3: TP9.T, U11.6 (DIO3)
SX1261_RFIN: C68.2, L22.2, U11.22 (RFI_N)
SX1261_RFIP: C73.1, L22.1, U11.21 (RFI_P)
SX1261_RST: R38.1, R60.1, U11.15 (NRESET), U12.18 (PA8)
SX1302_GPIO8: U1.53 (GPIO8), U12.26 (PB3)
TX_ON: R30.1, U1.63 (GPIO2)
TX_RX_SW: R16.2, U1.12 (RADIO_CTRL2)
VCCIO: C3.2, C19.2, C20.2, C25.2, C28.2, C41.2, C42.2, C45.2, C47.2, C76.2, C80.2, C83.2, C86.2, C87.2, C88.2, C89.2, C90.2, Q8.3 (D), R33.1, R34.2, R56.1, R58.1, R65.1, R68.1, R71.1, R80.2, TP1.T, U1.14 (VCC_IO), U1.30 (VCC_IO), U1.47 (VCC_IO), U1.61 (VCC_IO), U12.1 (VDD), U12.5 (VDDA), U12.17 (VDD), U13.3 (VDD)
VCC_1V2: C12.2, C13.2, C23.2, C24.2, C29.2, C40.2, C43.2, C44.2, C71.2, C72.2, L5.2, R79.1, R83.2, TP14.T, U1.5 (VCC_CORE), U1.23 (VCC_CORE), U1.40 (VCC_CORE), U1.56 (VCC_CORE), U6.5 (OUT)
VCC_FEM: C26.2, C27.2, C49.2, C50.2, C51.2, C55.2, FB1.2, L2.2, R2.2, TP6.T, U3.5 (VOUT)
VCC_RADIO: C21.2, C32.2, C33.2, C35.2, C39.2, C48.2, C67.1, L4.2, L7.1, L15.1, R7.2, R36.1, R38.2, R42.2, TP10.T, U4.5 (VOUT), U5.2 (VDD_IN), U5.9 (VBAT_RF), U5.10 (VBAT_DIO), U7.2 (VDD_IN), U7.9 (VBAT_RF), U7.10 (VBAT_DIO), U11.10 (VBAT), U11.11 (VBAT_IO)
VIN: C15.2, C22.2, C30.2, C31.2, C69.2, C70.2, J1.2 (3V3), J1.24 (3V3), J1.39 (3V3), J1.41 (3V3), J1.52 (3V3), Q8.2 (S), R2.1, R7.1, R8.2, R47.1, R78.1, R82.1, TP4.T, U3.1 (VIN), U4.1 (VIN), U6.2 (VIN)

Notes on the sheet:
V1.0
Initial Release
2020/01/02
Vincent
50ohm Impedence
3.3V
300mA
1.2V
500mA
100mA
USB
868
915
SPI
For Power-up delay
V1.1
Add power up delay circuit at VCCIO
Add power up reset circuit for SX1302
Change pins refer to Semtech V3 Schematic
2021/02/18



Board: 4 copper layers, 30.0 x 51.0 mm, 244 parts (68 on the bottom side), 162 nets.

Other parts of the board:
U$45: SEEED-SILK-TNAME-280*268MIL

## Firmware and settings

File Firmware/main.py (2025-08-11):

import board

from kmk.kmk_keyboard import KMKKeyboard
from kmk.keys import KC
from kmk.scanners import DiodeOrientation
from kmk.modules.encoder import EncoderHandler
from kmk.extensions.media_keys import MediaKeys

from kmk.modules.layers import Layers






keyboard = KMKKeyboard()
layers = Layers()
encoder_handler = EncoderHandler()
keyboard.modules.append(layers)
keyboard.modules.append(encoder_handler)
keyboard.extensions.append(MediaKeys())


# Define matrix pins based on the schematic, using GP pins
keyboard.col_pins = (board.GP0, board.GP1, board.GP2)  # COLUMN_1, COLUMN_2, COLUMN_3
keyboard.row_pins = (board.GP5, board.GP4, board.GP3)  # ROW_A, ROW_B, ROW_C
keyboard.diode_orientation = DiodeOrientation.COL2ROW



# Define keymap
keyboard.keymap = [
    [
        KC.A, KC.B, KC.C,
        KC.D, KC.E, KC.F,
        KC.G, KC.H, KC.I
    ]
]

# Configure encoder based on the schematic, using GP pins
encoder_handler.pins = ((board.GP10, board.GP9, board.GP8),)  # ENCA, ENCB, ENC_SWITCH
# Encoder map
encoder_handler.map = [(
    (KC.VOLU, KC.VOLD),
    KC.MUTE  # This will be triggered when the encoder is pressed
)]

if __name__ == '__main__':
    keyboard.go()

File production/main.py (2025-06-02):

import board

from kmk.kmk_keyboard import KMKKeyboard
from kmk.keys import KC
from kmk.scanners import DiodeOrientation
from kmk.modules.encoder import EncoderHandler
from kmk.extensions.media_keys import MediaKeys
from kmk.modules.layers import Layers

keyboard = KMKKeyboard()
encoder_handler = EncoderHandler()
keyboard.modules.append(encoder_handler)
keyboard.modules.append(Layers())
keyboard.extensions.append(MediaKeys())

keyboard.col_pins = (board.GP0, board.GP1, board.GP2)
keyboard.row_pins = (board.GP3, board.GP4, board.GP5)
keyboard.diode_orientation = DiodeOrientation.COL2ROW

encoder_handler.pins = ((board.GP6, board.GP7, board.GP8, False),)

VOLUME_UP = KC.AUDIO_VOL_UP
VOLUME_DOWN = KC.AUDIO_VOL_DOWN

keyboard.keymap = [
    [
        KC.N1,  KC.N2,  KC.N3,
        KC.N4,  KC.N5,  KC.N6,
        KC.N7,  KC.N8,  KC.N9,
    ]
]

encoder_handler.map = [
    ((VOLUME_UP, VOLUME_DOWN),)
]

if __name__ == '__main__':
    keyboard.go()

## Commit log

2025-06-01 Completed journaling Schematics and PCB design, will begin adding files later
2025-06-02 added all files to the commit, completed README
    [Case Bottom.step, Case Top.step, Grove - Vision AI Module V2.kicad_pcb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]
2025-06-04 fixed pcb, added to journal
    [HackpadAllan-B_Cu.gbr, HackpadAllan-B_Mask.gbr, HackpadAllan-B_Paste.gbr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]
2025-06-07 idek tbh finished everysthing so hopefully this doesn't mess anything up
    [HackpadAllan-B_Cu.gbr, HackpadAllan-B_Mask.gbr, HackpadAllan-B_Paste.gbr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]
